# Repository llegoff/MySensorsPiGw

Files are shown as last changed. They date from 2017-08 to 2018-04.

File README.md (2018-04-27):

[:fr:](LISEZMOI.md) [:uk:](README.md)

MySensorsPiGw
=============
MySensors RFM69 &amp; NRF24L Gateway for Raspberry Pi (zero &amp; B)

see
https://www.mysensors.org/build/raspberry

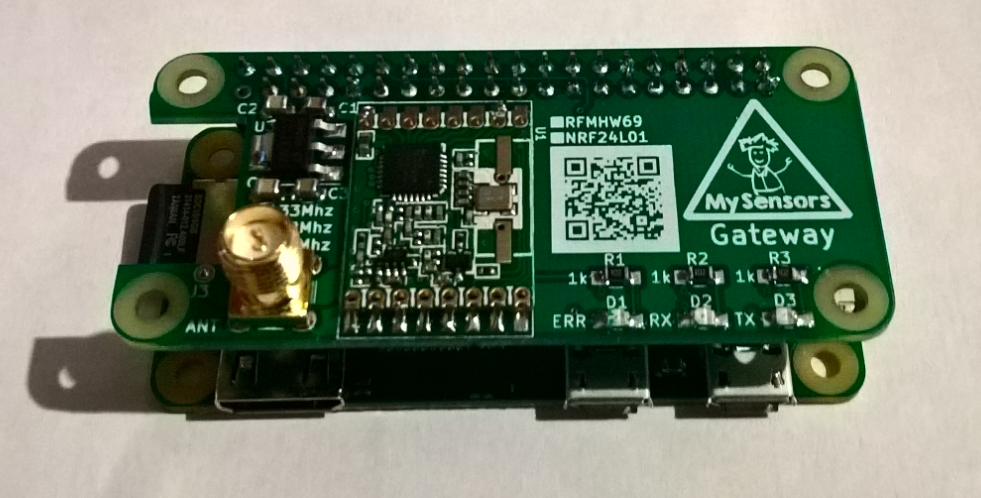
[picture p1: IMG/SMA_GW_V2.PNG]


revision:

v1
- bad width of antenna track

v2
- change width of antenna track
- add 3.3v regulator
- add C1, C2, C3, C4

v3 
- add second NRF24L01 on SPI1
- add capacitor C5 C6
- add status leds D4 D5 D6
- change J3 position

Schema
-------
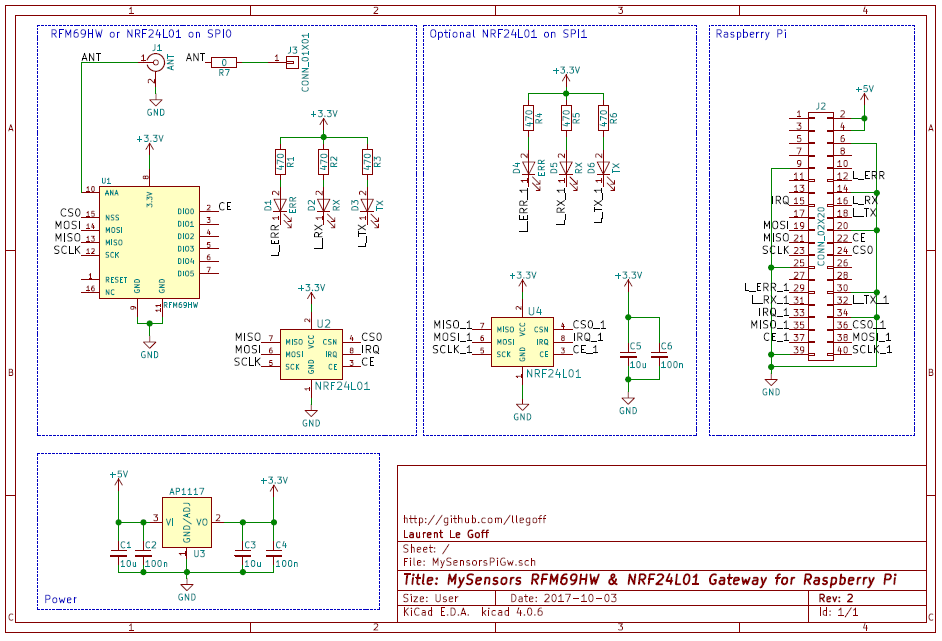
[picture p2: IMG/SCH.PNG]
sch


PCB
---
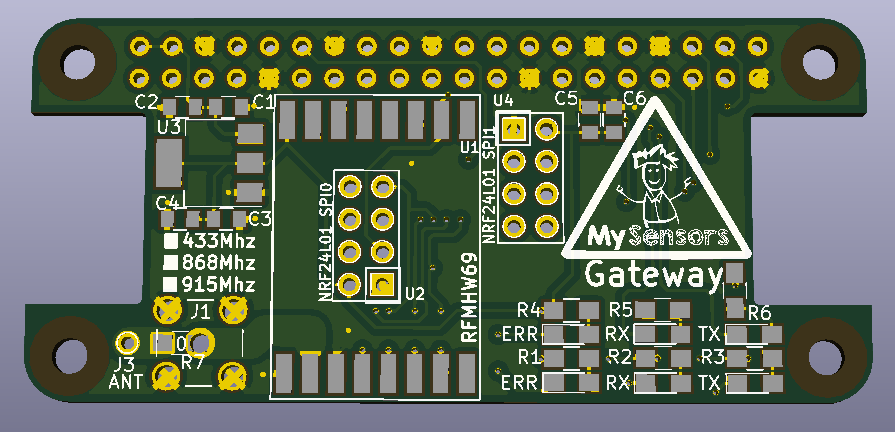
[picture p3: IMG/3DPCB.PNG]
Top

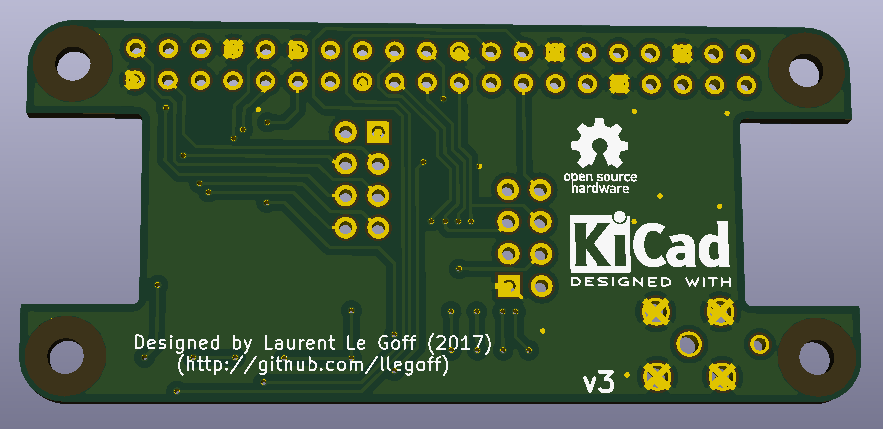
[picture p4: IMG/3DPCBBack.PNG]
Bottom


RFM69HW 
-------
RFM69HW is connected to SPI0

Download dev branch

    git clone https://github.com/mysensors/MySensors.git --branch development
    cd MySensors

configure (Ethernet gateway)

    ./configure --my-transport=rfm69 --my-rfm69-frequency=868 --my-is-rfm69hw --my-port=5003 --my-leds-err-pin=12 --my-leds-rx-pin=16 --my-leds-tx-pin=18
    make
    
running

    sudo ./bin/mysgw
    
install

    sudo make install
    
NRF24L01 on SPI0
----------------
Download master branch

    git clone https://github.com/mysensors/MySensors.git --branch master
    cd MySensors

configure (Ethernet gateway)

    ./configure --my-transport=nrf24 --my-rf24-irq-pin=15 --my-port=5003 --my-leds-err-pin=12 --my-leds-rx-pin=16 --my-leds-tx-pin=18
    make

running

    sudo ./bin/mysgw

install

    sudo make install

NRF24L01 on SPI1
----------------

It's experimental, see https://forum.mysensors.org/topic/7702/double-spi-radio-raspberry-pi

in /boot/config.txt add 

    //*** uncomment for pi3 ***
    //dtoverlay=pi3-disable-bt
    
    dtparam=spi=on
    //change spi1 cs0 to gpio16 pin 36
    dtoverlay=spi1-1cs,cs0_pin=16  

reboot the PI

    sudo reboot

copy the source

    cp -r MySensors MySensorsSecond
    cd MySensorsSecond

edit file `Makefile` : replace the string `mysgw` by `mysgwSecond` (in nano use Ctrl + \ )

copy file `initscripts/mysgw.systemd` and `initscripts/mysgwSecond.sysvinit` to `initscripts/mysgwSecond.systemd` and `initscripts/mysgwSecond.sysvinit` 
    
    cp initscripts/mysgw.systemd initscripts/mysgwSecond.systemd
    cp initscripts/mysgwSecond.sysvinit initscripts/mysgwSecond.sysvinit
    
edit file `initscripts/mysgwSecond.systemd` and `initscripts/mysgwSecond.sysvinit` : replace the string `mysgw` by `mysgwSecond` (in nano use Ctrl + \ ) and replace the string `MySensors Gateway` by `MySensors Gateway 2`

copy file mysgw.cpp to mysgwSecond.cpp 

    cp examples_linux/mysgw.cpp examples_linux/mysgwSecond.cpp

configure the second instance 

    ./configure --my-transport=nrf24 --my-rf24-irq-pin=33 --my-rf24-ce-pin=37 --my-rf24-cs-pin=36 --spi-spidev-device=/dev/spidev1.0 --spi-driver=SPIDEV --my-port=5004 --my-leds-err-pin=29 --my-leds-rx-pin=31 --my-leds-tx-pin=32
    make
    
running

    sudo ./bin/mysgwSecond

install

    sudo make install

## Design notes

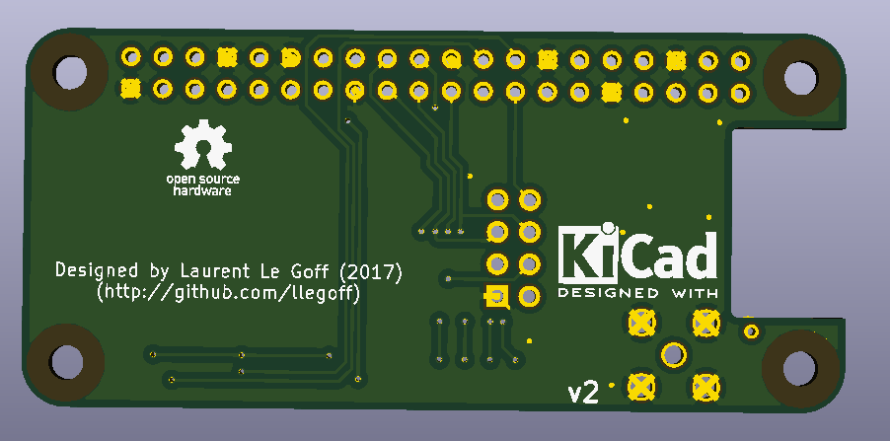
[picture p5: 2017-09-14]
IMG/3DPCBBackv2.PNG

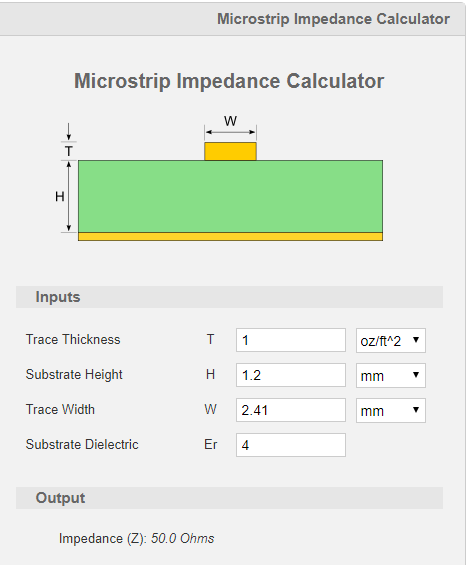
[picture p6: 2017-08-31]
IMG/50ohm_line.PNG

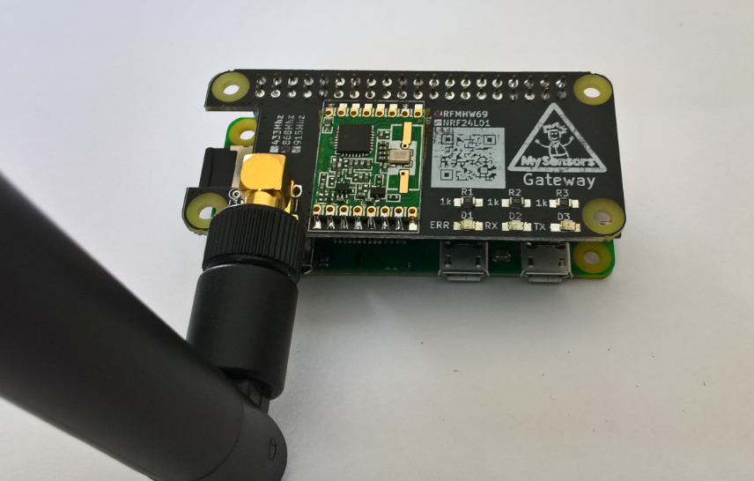
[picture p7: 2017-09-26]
IMG/SMA_GW.PNG

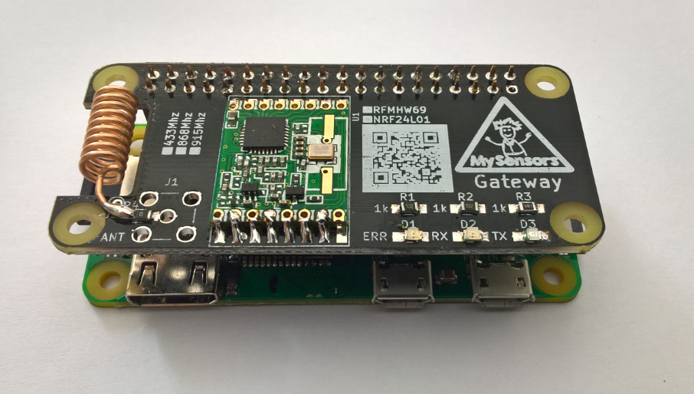
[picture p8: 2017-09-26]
IMG/wire_GW.PNG

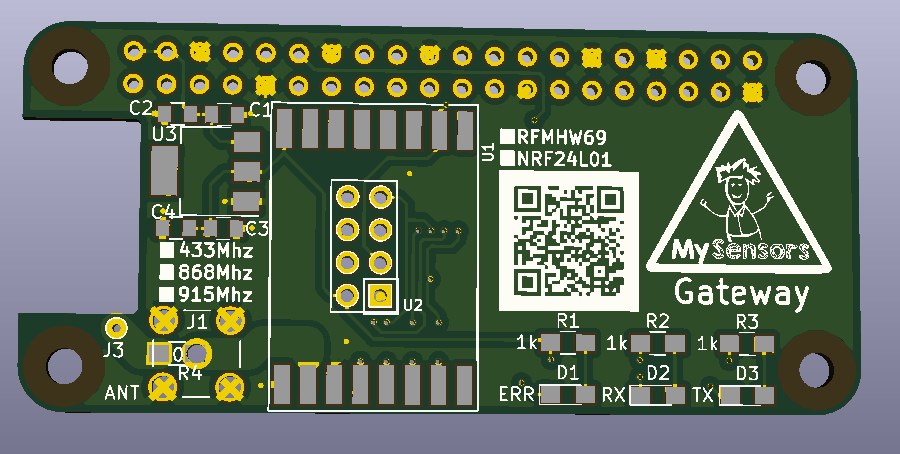
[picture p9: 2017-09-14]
IMG/3DPCBv2.PNG

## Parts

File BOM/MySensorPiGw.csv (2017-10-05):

Parts | Qty | Don't Put Opt | Value | Package | Description | MPN
D1 | 1 |  | Red LED | 0805 | LED err
D2 | 1 |  | Yellow LED | 0805 | LED rx
D3 | 1 |  | Green LED | 0805 | LED tx
D4 | 1 | X | Red LED | 0805 | LED err
D5 | 1 | X | Yellow LED | 0805 | LED rx
D6 | 1 | X | Green LED | 0805 | LED tx
R1, R2, R3 | 3 |  | 1k | 0805 | Resistor
R4, R5, R6 | 3 | X | 1k | 0805 | Resistor
R7 | 1 | X | 0R | 0805 | Resistor
C1, C3 | 2 |  | 10u | 0805 | capacitor
C2, C4 | 2 |  | 100n | 0805 | capacitor
C5 | 1 | X | 10u | 0805 | capacitor
C6 | 1 | X | 100n | 0805 | capacitor
U1 | 1 |  | RFM69HW | RFM69HW | Hoperf radio
R1, R2, R3 | 3 |  | 1k | 0805 | Resistor
U2, U4 | 1 | X | NRF24L01 | NRF24L01 | 2.4ghz radio
U3 | 1 |  | AP1117 | 3.3v | sot23 | 3.3v regulator
J1 | 1 |  | SMA connector | SMA connector
J2 | 1 |  | 2x20 pinheader | Female header 2.54mm
J3 | 1 | X | Antenna

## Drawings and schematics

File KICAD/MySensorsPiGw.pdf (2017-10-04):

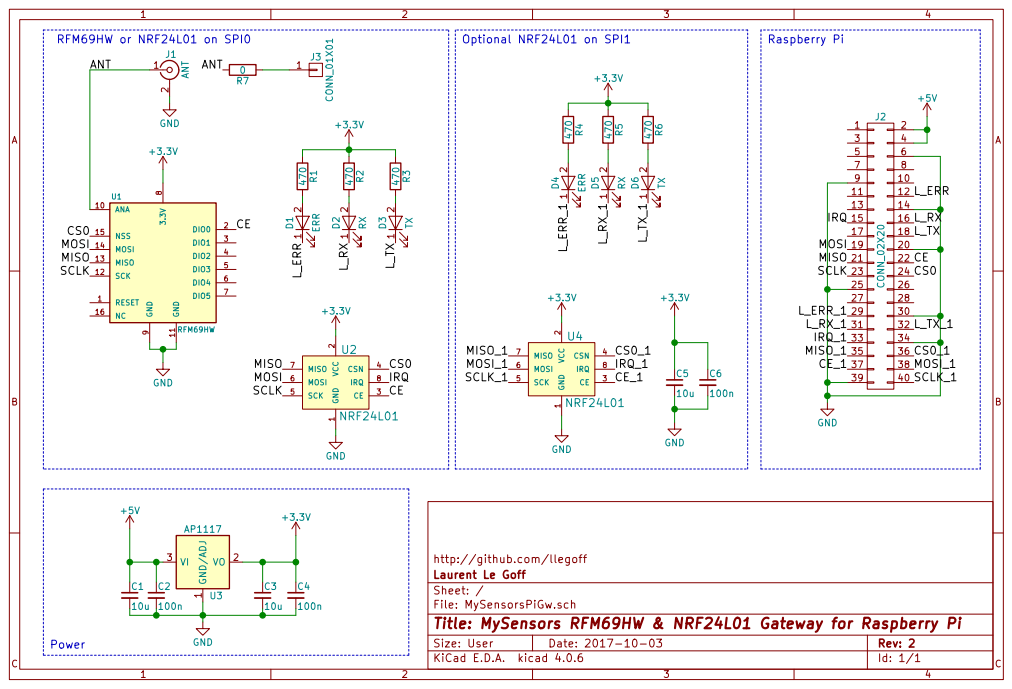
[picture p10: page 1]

9 ANA 10 GND 11 SCK 12 MISO 13 MOSI 14 NSS 15 NC 16 U1 RFM69HW
MOSI
MISO
SCLK

2 CE 3 CSN 4 SCK 5 MOSI 6 MISO 7

Id: 1/1 Title: MySensors RFM69HW & NRF24L01 Gateway for Raspberry Pi

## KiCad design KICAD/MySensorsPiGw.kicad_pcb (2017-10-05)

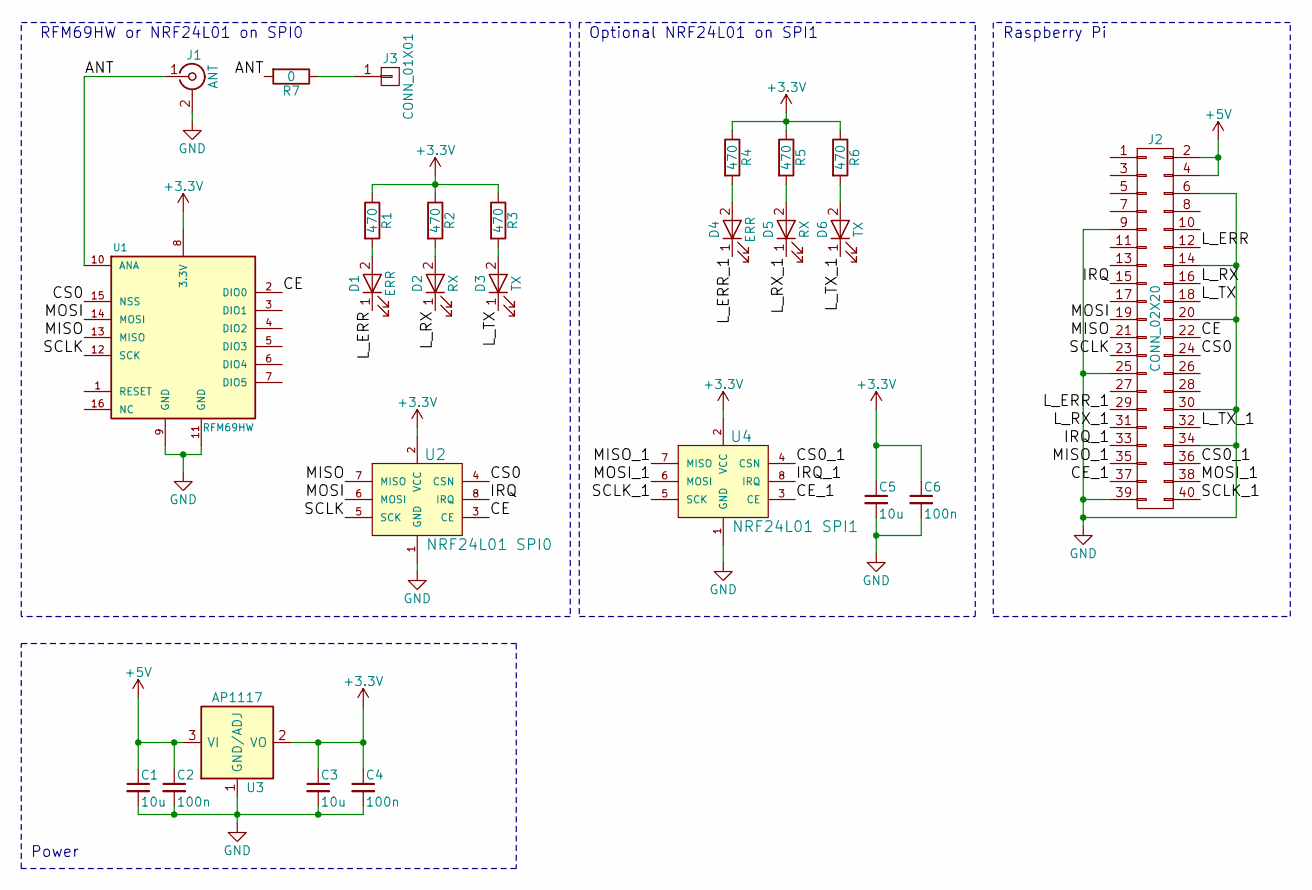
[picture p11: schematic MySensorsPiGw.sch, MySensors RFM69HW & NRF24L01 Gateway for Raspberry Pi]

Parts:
C1, C3, C5: 10u; C_0805
C2, C4, C6: 100n; C_0805
D1, D4: ERR; LED_0805_HandSoldering
D2, D5: RX; LED_0805_HandSoldering
D3, D6: TX; LED_0805_HandSoldering
J1: ANT; SMA_THT_Jack_Straight
J2: CONN_02X20; RaspberryPiZeroHAT
J3: CONN_01X01; PINTST
R1, R2, R3, R4, R5, R6: 470; R_0805_HandSoldering
R7: 0; R_0805_HandSoldering
U1: RFM69HW; RFM69HW_SMD_Handsoldering
U2: NRF24L01 SPI0; NRF24L01
U3: AP1117; SOT-223
U4: NRF24L01 SPI1; NRF24L01

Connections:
+3V3: C3.1, C4.1, C5.1, C6.1, R1.1, R2.1, R3.1, R4.1, R5.1, R6.1, U1.8 (3.3V), U2.2 (VCC), U3.2 (VO), U3.4 (VO), U4.2 (VCC)
+5V: C1.1, C2.1, J2.2, J2.4, U3.3 (VI)
/ANT: J1.1 (In), R7.2, U1.10 (ANA)
/CE: J2.22, U1.2 (DIO0), U2.3 (CE)
/CE_1: J2.37, U4.3 (CE)
/CS0: J2.24, U1.15 (NSS), U2.4 (CSN)
/CS0_1: J2.36, U4.4 (CSN)
/IRQ: J2.15, U2.8 (IRQ)
/IRQ_1: J2.33, U4.8 (IRQ)
/L_ERR: D1.1 (K), J2.12
/L_ERR_1: D4.1 (K), J2.29
/L_RX: D2.1 (K), J2.16
/L_RX_1: D5.1 (K), J2.31
/L_TX: D3.1 (K), J2.18
/L_TX_1: D6.1 (K), J2.32
/MISO: J2.21, U1.13 (MISO), U2.7 (MISO)
/MISO_1: J2.35, U4.7 (MISO)
/MOSI: J2.19, U1.14 (MOSI), U2.6 (MOSI)
/MOSI_1: J2.38, U4.6 (MOSI)
/SCLK: J2.23, U1.12 (SCK), U2.5 (SCK)
/SCLK_1: J2.40, U4.5 (SCK)
GND: C1.2, C2.2, C3.2, C4.2, C5.2, C6.2, J1.2 (Ext), J2.6, J2.9, J2.14, J2.20, J2.25, J2.30, J2.34, J2.39, U1.9 (GND), U1.11 (GND), U2.1 (GND), U3.1 (GND/ADJ), U4.1 (GND)
unnamed: D1.2 (A), R1.2
unnamed: D2.2 (A), R2.2
unnamed: D3.2 (A), R3.2
unnamed: D4.2 (A), R4.2
unnamed: D5.2 (A), R5.2
unnamed: D6.2 (A), R6.2
unnamed: J3.1, R7.1

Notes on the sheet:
Optional NRF24L01 on SPI1
RFM69HW or NRF24L01 on SPI0
Raspberry Pi
Power

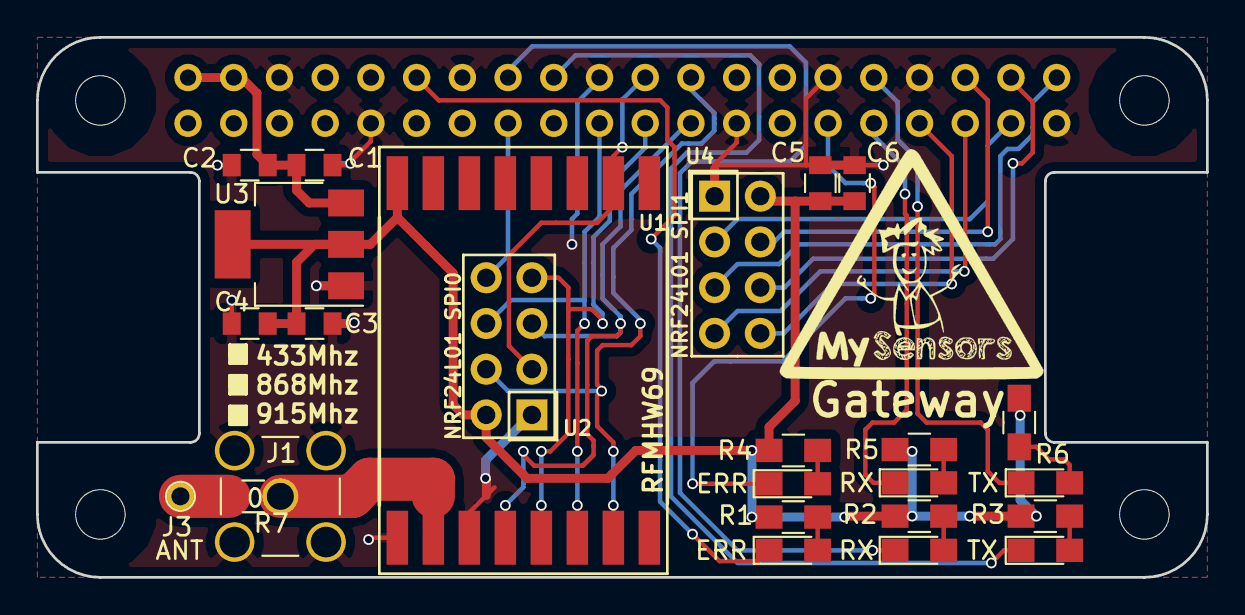
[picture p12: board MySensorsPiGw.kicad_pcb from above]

Board: 2 copper layers, 65.0 x 30.0 mm, 26 parts (0 on the bottom side), 29 nets.

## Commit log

2017-10-04 v3 Gerber
    [MySensorsPiGw.gbl, MySensorsPiGw.gbo, MySensorsPiGw.gbs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]
2017-10-04 v3 kicad
    [MySensorsPiGw.kicad_pcb, MySensorsPiGw.sch]
